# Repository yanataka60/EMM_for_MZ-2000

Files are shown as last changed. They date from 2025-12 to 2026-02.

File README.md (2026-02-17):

# EMMボード for MZ-2000

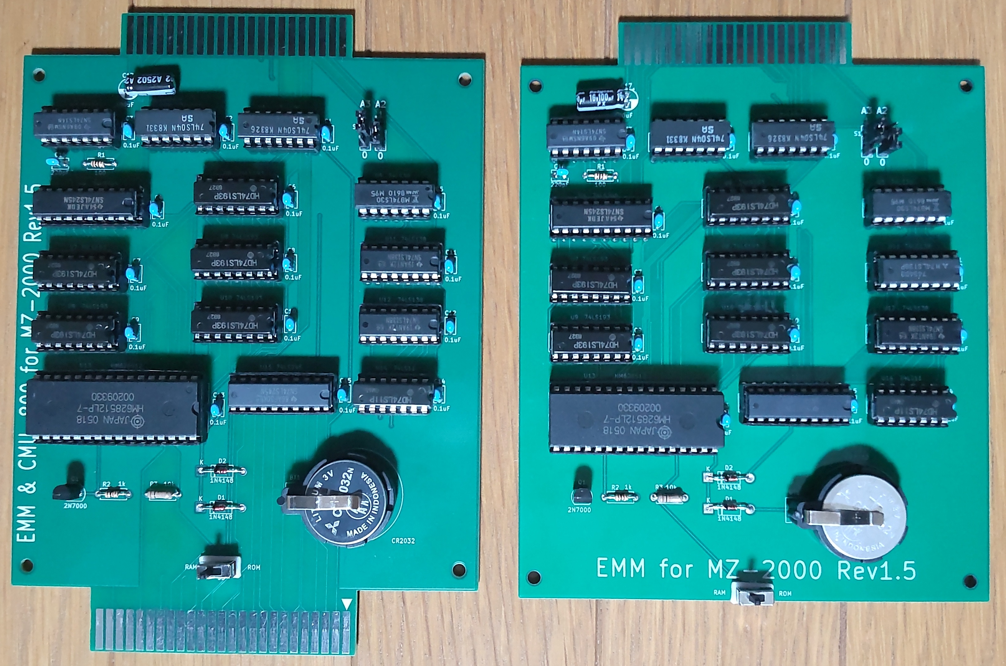
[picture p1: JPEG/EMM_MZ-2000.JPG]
TITLE


　MZ-2000、MZ-2200、MZ-80B、MZ-2500(2000モード、80Bモード)用の512K S-RAM EMMボードを作ってみました。

　特徴としては、

　1)I/Oポートは、I・Oデータ機器 PIO-3034互換なのでそのままPIO-3034(320K EMM)として使えます。

　2)CR-2032のバックアップにより電源を切ってもメモリ内容が保持されます。(Rev1.5のバックアップ期間は計算上数年は大丈夫です。)

　3)スイッチにより書込み禁止にできます。

　4)I/Oポートから直接EMMを読み書きすれば512K外部RAMとして使えます。

　5)MZ-2000_SDと併用すれば512KまるごとSDカードからLOAD、SAVEが可能です。

　6)ジャンパによりEMM0～EMM3のいずれかに設定して使えます。(MZ-2000_SDと併用するときはEMM0としては使えません。EMM1～EMM3として使ってください。)

　7)おまけでアドレスカウンタリセットを付けました。

　なお、MZ-2000、MZ-2200、MZ-80B、MZ2500本体の通常の電源ON/OFFでの正常動作は確認していますが、電源ON/OFFを瞬間的に繰り返すような無理な使い方をするとEMMのバックアップが正常に動作しないことがあります。電源ON/OFFを瞬間的に繰り返すと電源ユニットにもダメージが及ぶこともあるので電源ON/OFFは間をおいて行ってください。

## 回路図
　KiCadフォルダ内にEMMとEMM&CMUの２種類があります。CMU-800を接続するにはCMU-800から出ているフラットケーブルのカードエッジコネクタを接続する必要があり、CMU-800所有者がスロット不足に悩まなくて済むようカードエッジをつけ足したもので回路は全く同じものです。

　お好きな方を使ってください。

[回路図](https://github.com/yanataka60/EMM_for_MZ-2000/blob/main/Kicad/EMM/MZ-2000_EMM.pdf)
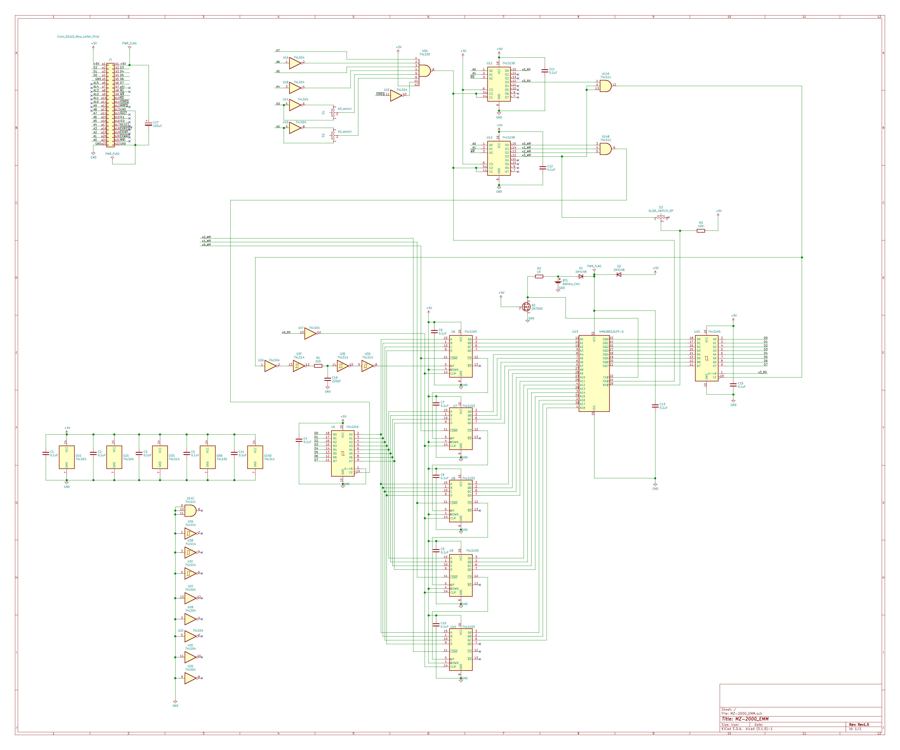
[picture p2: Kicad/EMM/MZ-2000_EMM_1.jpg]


[回路図](https://github.com/yanataka60/EMM_for_MZ-2000/blob/main/Kicad/EMM%26CMU/MZ-2000_EMM_CMU.pdf)
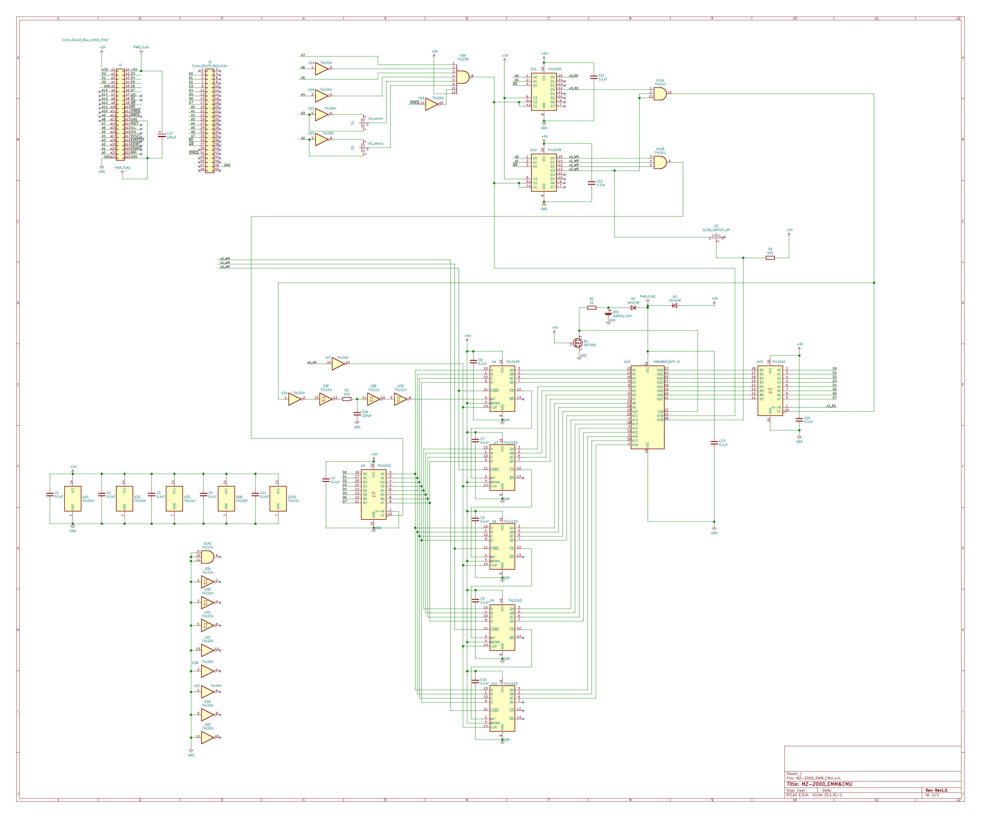
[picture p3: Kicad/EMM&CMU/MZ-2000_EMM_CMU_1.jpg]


## 部品表
|番号|品名|数量|備考|
| --- | --- | --- | --- |
|C1-C15|積層セラミックコンデンサ 0.1uF|15||
|C16|積層セラミックコンデンサ 220pF|1||
|C17|電解コンデンサ 100uF|1||
|D1-D2|ダイオード 1N4148|2|1S4から1N4148に変更|
|Q1|FET 2N7000|1||
|R1|カーボン抵抗 100Ω|1||
|R2|カーボン抵抗 1k|1||
|R3|カーボン抵抗 10k|1||
|S1,S2|3Pスライドスイッチ又は1x3ピンヘッダとジャンパーピン|2|秋月電子通商 SS12D01G4又はPH-1X3SG,MJ-254-6BK等|
|S3|3Pスライドスイッチ|1|秋月電子通商 SS12D01G4|
|U1,U2|74LS04|2|樫木総業等|
|U3|74LS14|1|樫木総業等|
|U4,U15|74LS245|2|樫木総業等|
|U5|74LS30|1|樫木総業等|
|U6-U10|74LS193|5|樫木総業等|
|U11,U12|74LS138|2|樫木総業等|
|U13|SRAM HM628512|1|注1)|
|U14|74LS11|1|樫木総業等|
|BT1|ボタン電池基板取付用ホルダー CR2032用(小型タイプ)|1|秋月電子通商 CH25-2032LFなど|

注1)DIPで設計しています。SOPを入手した場合にはこちらの変換基板を使うことで装着できます。

https://github.com/yanataka60/SOPtoDIP32

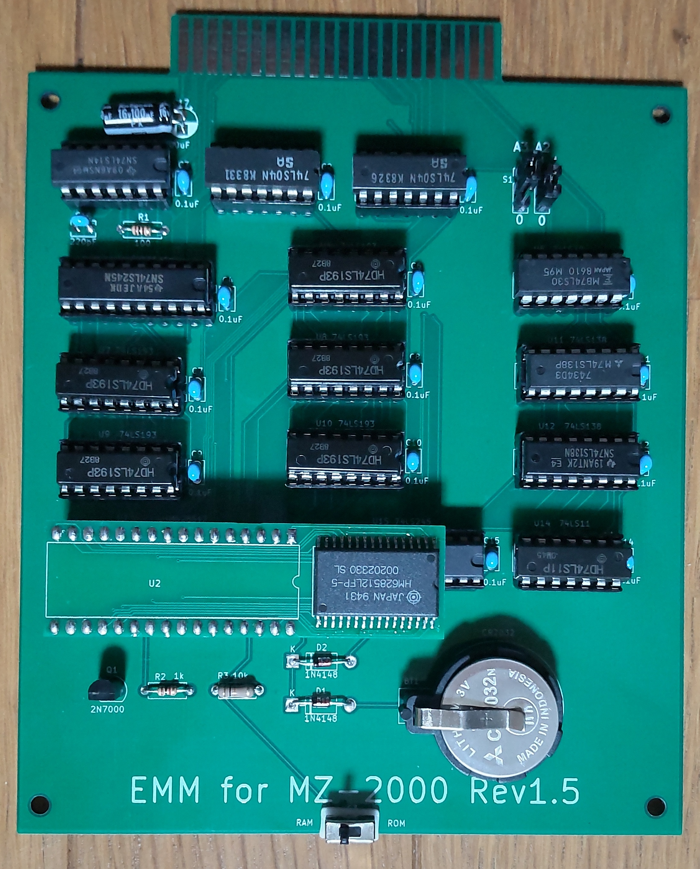
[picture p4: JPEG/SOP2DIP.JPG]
SOP2DIP


## I/Oポート
### EMM0
ジャンパピンA3、A2とも0の位置にします。

#### 注)EMM0の設定ではMZ-2000_SDと共存できません。MZ-2000_SDと共存させたい場合は、EMM1～EMM3の設定で使ってください。

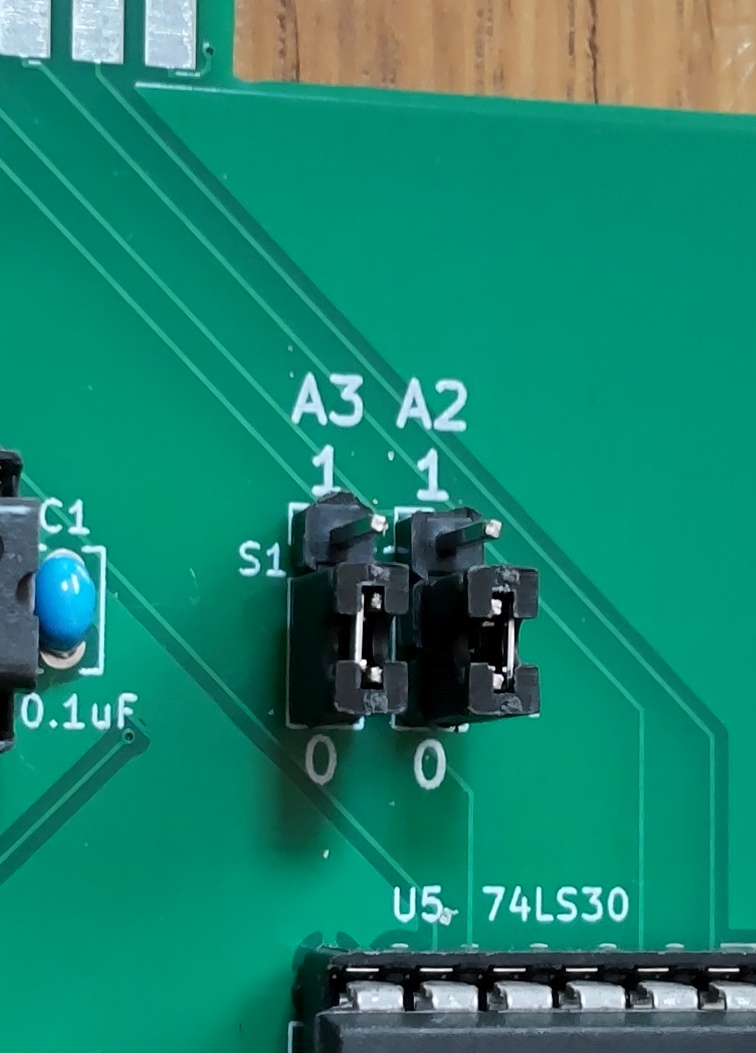
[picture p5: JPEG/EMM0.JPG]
EMM0


|アドレス|R/W|説明|
| --- | --- | --- |
|A0h|R|アドレスカウンタリセット|
|A0h|W|アドレスカウンタ Bit[7:0]|
|A1h|W|アドレスカウンタ Bit[15:8]|
|A2h|W|アドレスカウンタ Bit[18:16]|
|A3h|R|データ読み出し:アドレスカウンタ+1|
|A3h|W|データ書き込み:アドレスカウンタ+1|
### EMM1
ジャンパピンA3を0、A2を1の位置にします。

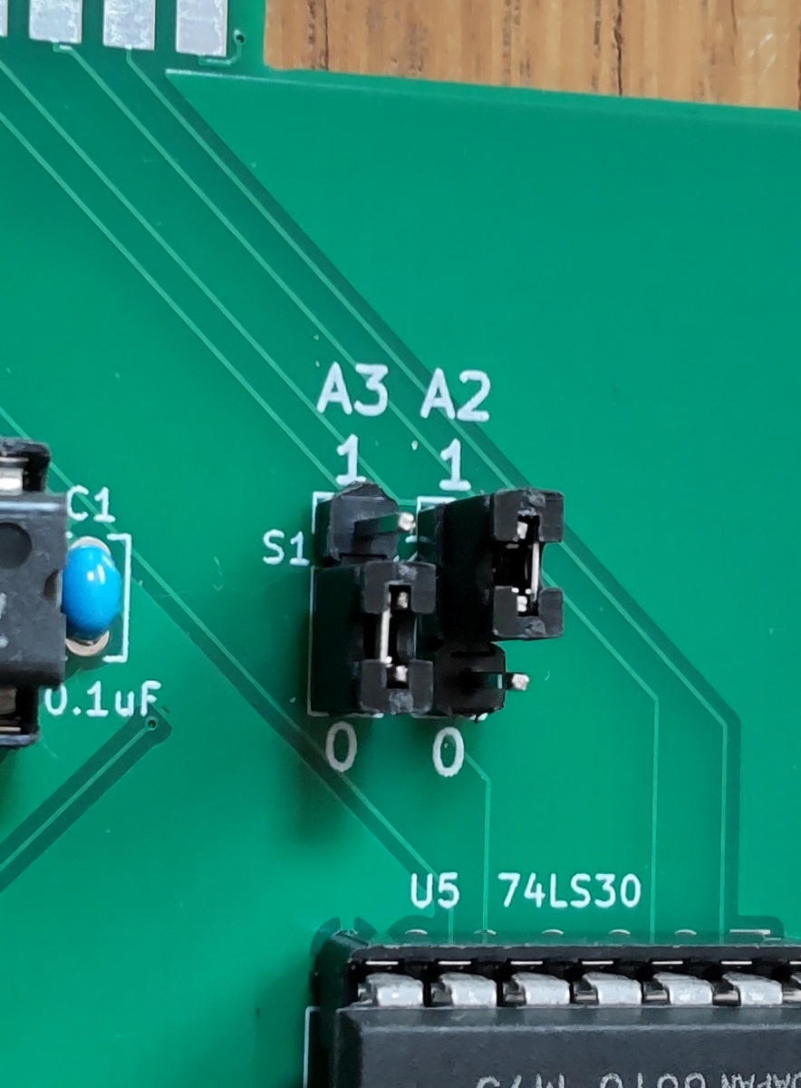
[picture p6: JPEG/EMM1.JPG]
EMM1


|アドレス|R/W|説明|
| --- | --- | --- |
|A4h|R|アドレスカウンタリセット|
|A4h|W|アドレスカウンタ Bit[7:0]|
|A5h|W|アドレスカウンタ Bit[15:8]|
|A6h|W|アドレスカウンタ Bit[18:16]|
|A7h|R|データ読み出し:アドレスカウンタ+1|
|A7h|W|データ書き込み:アドレスカウンタ+1|
### EMM2
ジャンパピンA3を1、A2を0の位置にします。

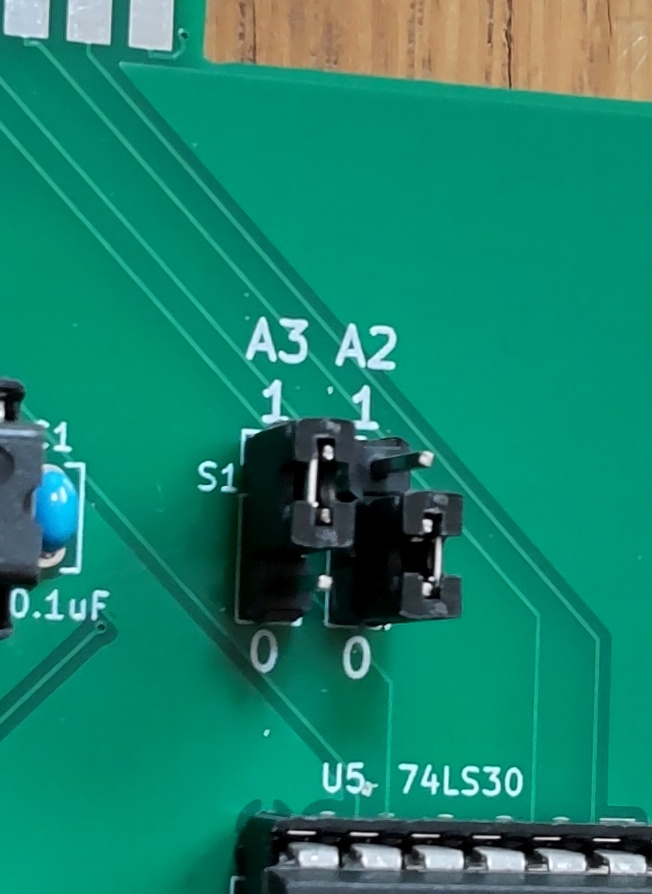
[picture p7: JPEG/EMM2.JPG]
EMM2


|アドレス|R/W|説明|
| --- | --- | --- |
|A8h|R|アドレスカウンタリセット|
|A8h|W|アドレスカウンタ Bit[7:0]|
|A9h|W|アドレスカウンタ Bit[15:8]|
|AAh|W|アドレスカウンタ Bit[18:16]|
|ABh|R|データ読み出し:アドレスカウンタ+1|
|ABh|W|データ書き込み:アドレスカウンタ+1|
### EMM3
ジャンパピンA3、A2とも1の位置にします。

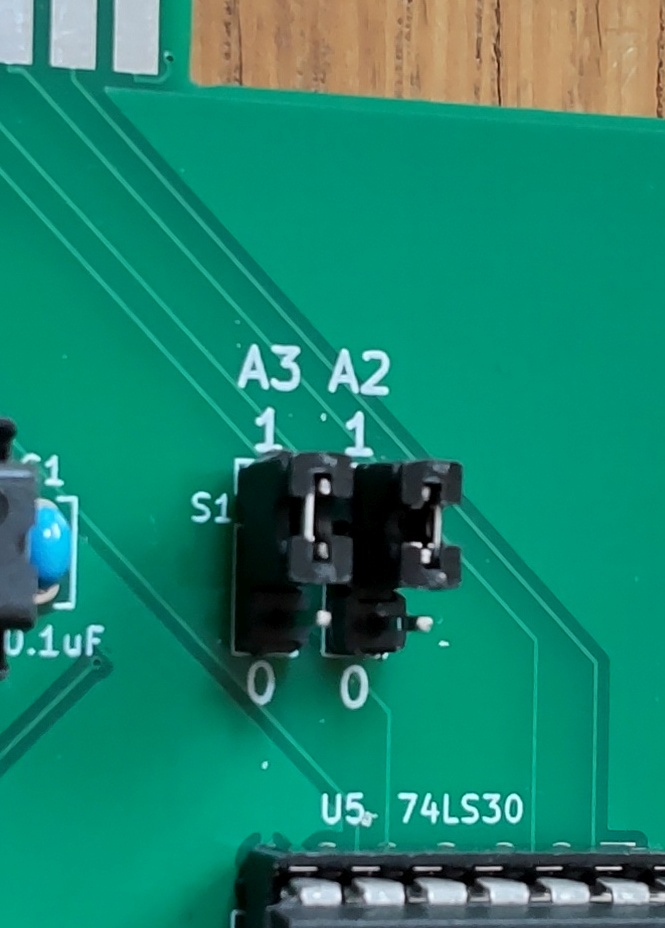
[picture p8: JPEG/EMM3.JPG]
EMM3


|アドレス|R/W|説明|
| --- | --- | --- |
|ACh|R|アドレスカウンタリセット|
|ACh|W|アドレスカウンタ Bit[7:0]|
|ADh|W|アドレスカウンタ Bit[15:8]|
|AEh|W|アドレスカウンタ Bit[18:16]|
|AFh|R|データ読み出し:アドレスカウンタ+1|
|AFh|W|データ書き込み:アドレスカウンタ+1|

## SAMPLEプログラム
　SAMPLEフォルダ内にEMMANIME、EMMMENU、EMMCHECK、EMMTESTを置きました。

　使い方については、各フォルダ内のREADME.mdを参照してください。

## EMMからの起動
　せっかくバッテリーバックアップに対応させたのでMZ-2000_SDの起動時にEMMから起動できるようにしてみました。

　MZ-2000_SDのROMをEMM対応BOOT LOADERに書き換える必要があります。

　MZ-2000_SDの「EMMボード for MZ-2000からの起動」を参照してください。

　https://github.com/yanataka60/MZ-2000_SD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

## 初期基板をバッテリーバックアップ対応とするには
#### 2026.2.16 Rev1.5基板ではバックアップ時間が飛躍的に増加し、ICに負荷をかけない回路となりました。バッテリーバックアップを使うなら出来ればRev1.5基板に更新してください。

　以下に示すパターンカット、ジャンパ、追加部品(抵抗10k×1本、ダイオード1S4×1本)で改造することで初期基板をバッテリーバックアップ対応とすることが可能です。

　ただし、パターンカット個所がU2 74LS04 ICソケット内側にもあるのでEMMボード組み立て済みの場合にはICソケットを一旦取り外す必要があります。

　また、EMM基板とEMM&CMU基板ではパターンカットの個所が若干違いがあります。ジャンパは共通です。

### EMM基板パターンカット個所
　U2 74LS04の3Pin、5Pin、9Pin、11PinをGNDから切り離します。

　U13 HM628512の29PinとU14 74LS11 13Pinとの接続をカットします。

　U13 HM628512の22、24Pin、R2 抵抗 10Kとの接続点とU12 74LS138 5Pinとの接続をカットします。

部品面全体
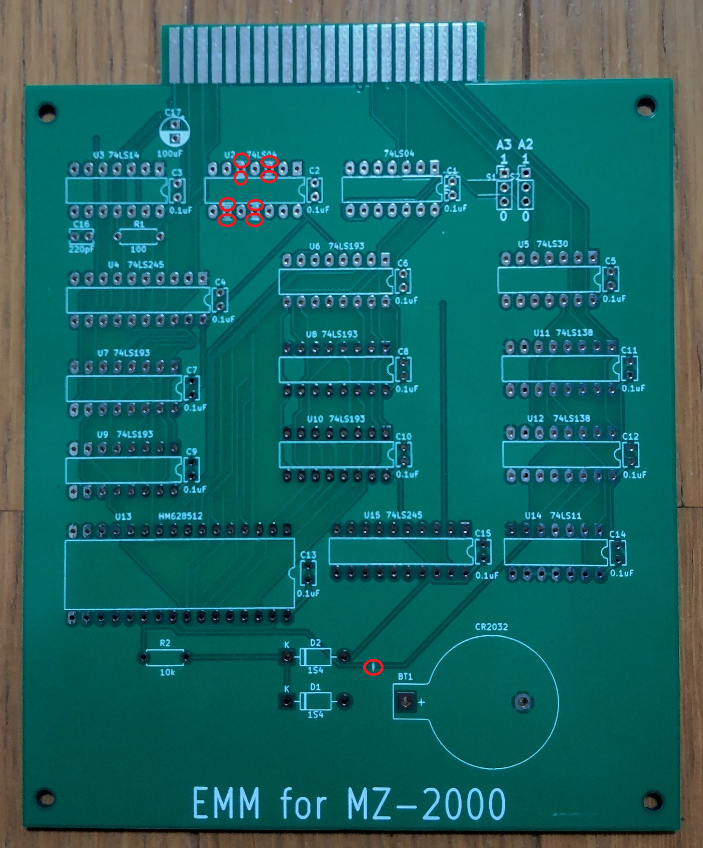
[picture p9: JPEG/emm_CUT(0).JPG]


部品面拡大1
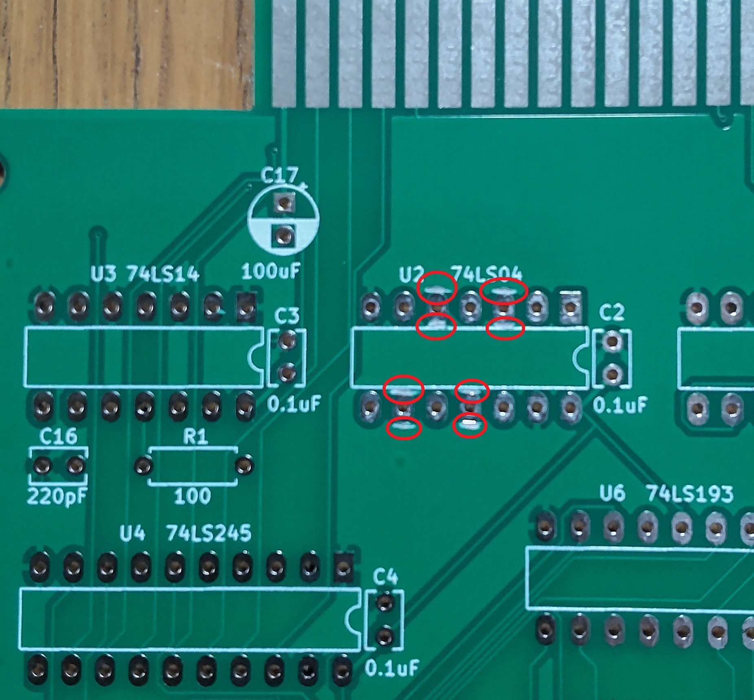
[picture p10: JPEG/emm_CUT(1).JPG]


部品面拡大2
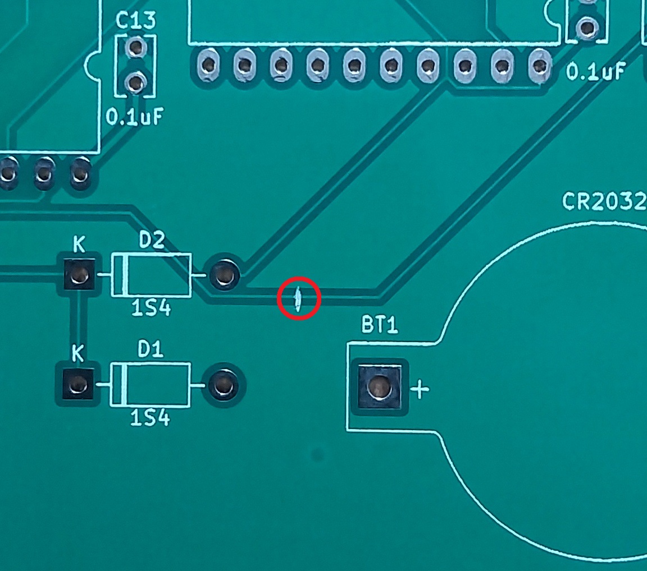
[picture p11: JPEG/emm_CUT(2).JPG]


ハンダ面全体
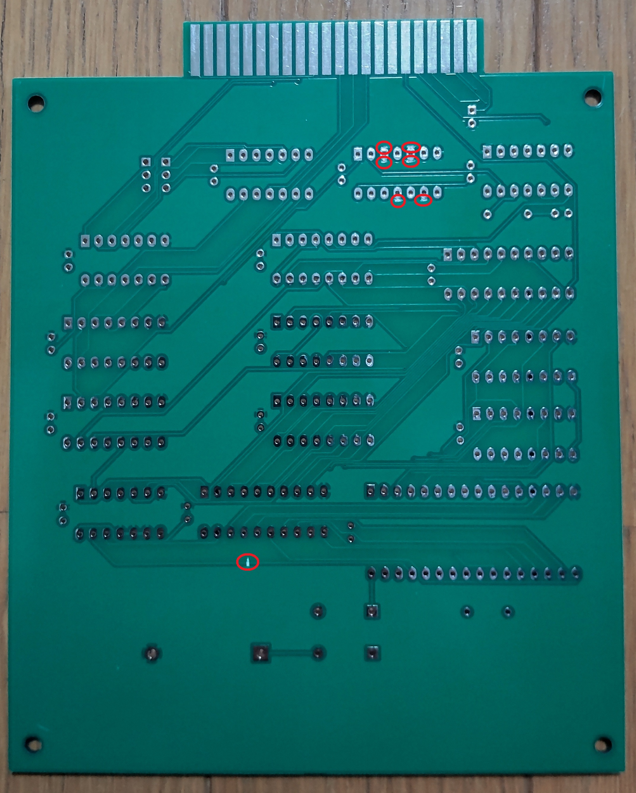
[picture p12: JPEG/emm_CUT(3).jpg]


ハンダ面拡大1
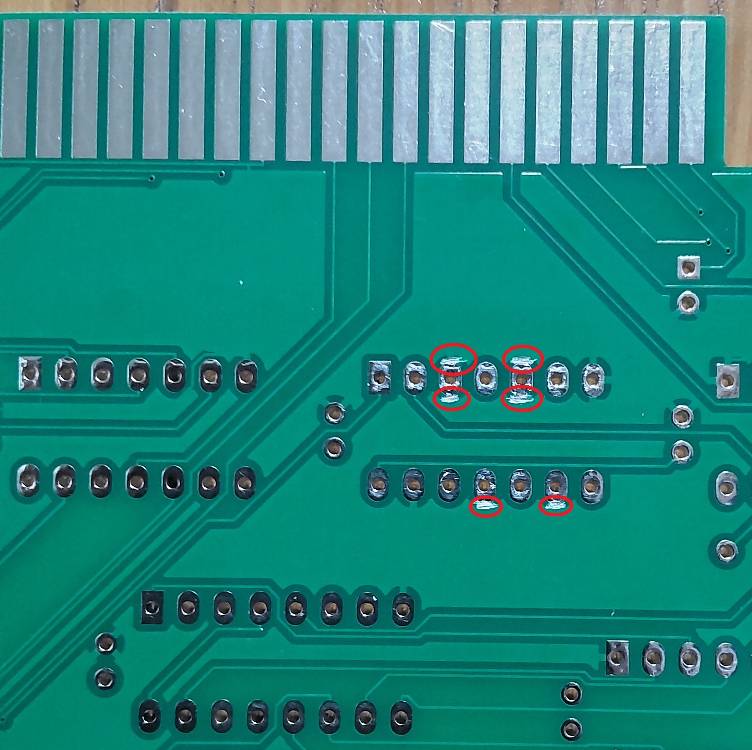
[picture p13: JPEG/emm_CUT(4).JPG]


ハンダ面拡大2
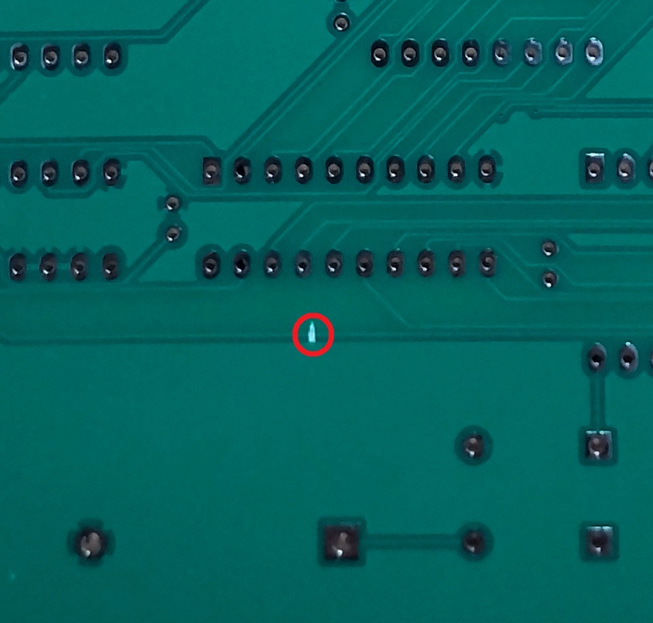
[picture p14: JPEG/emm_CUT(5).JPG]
cut5


### EMM&CMU基板パターンカット個所
　切り離すポイントはEMM基板と同じですが、基板上のカット位置は若干異なります。

部品面全体
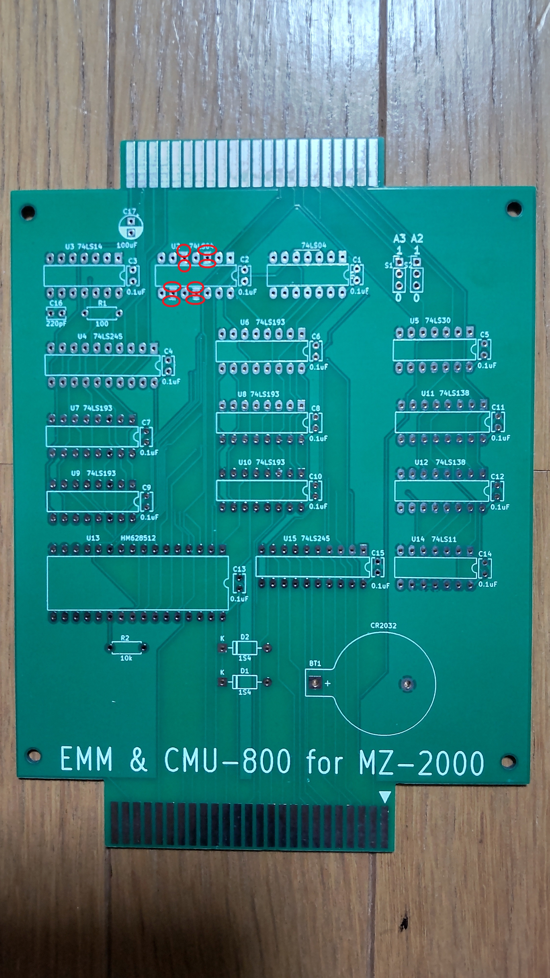
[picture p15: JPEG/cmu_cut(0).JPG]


部品面拡大1
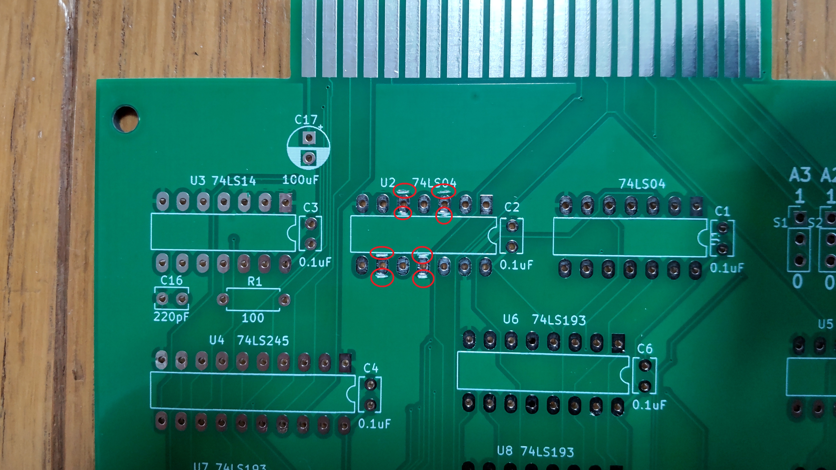
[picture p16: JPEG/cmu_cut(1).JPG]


ハンダ面全体
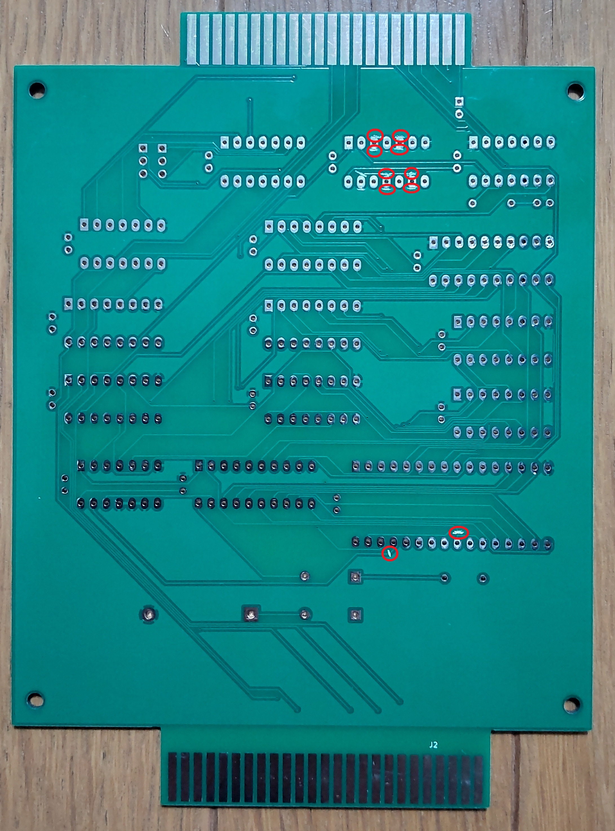
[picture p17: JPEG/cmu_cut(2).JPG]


ハンダ面拡大1
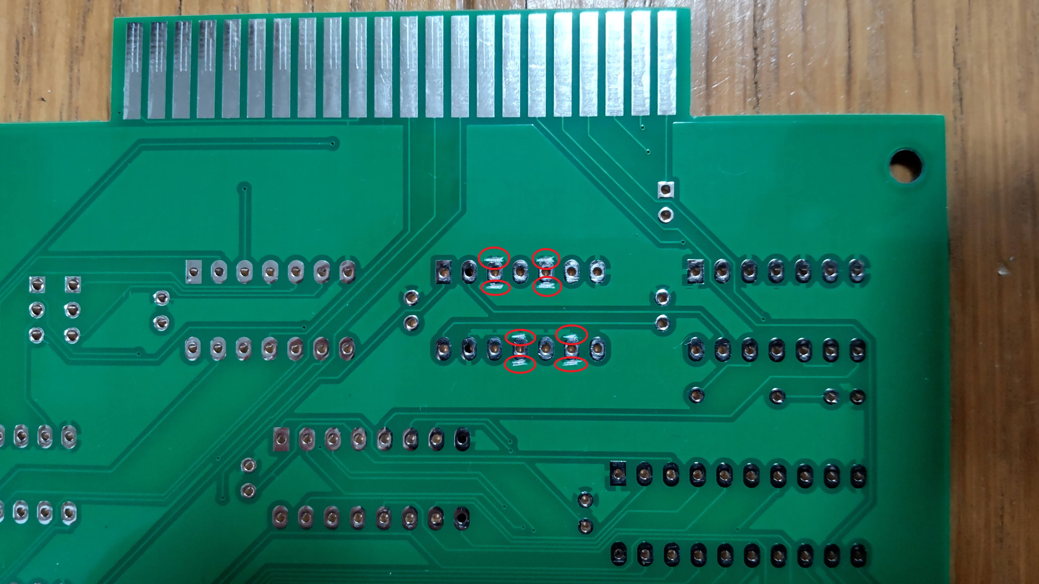
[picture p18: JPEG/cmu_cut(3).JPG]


ハンダ面拡大2
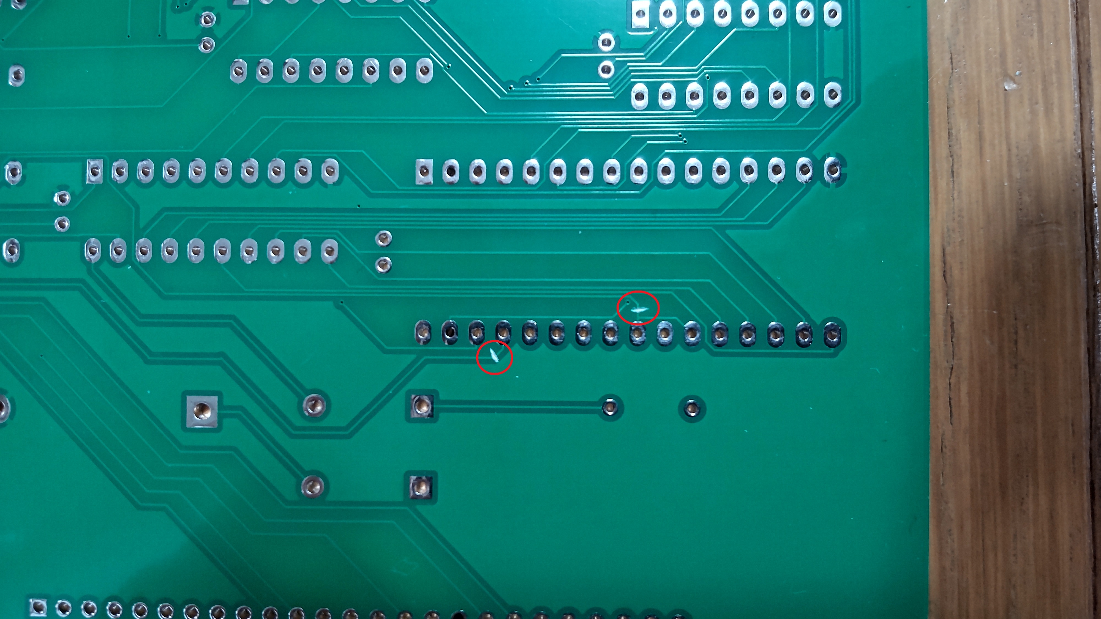
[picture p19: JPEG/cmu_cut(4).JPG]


### ジャンパ個所
　U12 74LS138 5PinとU2 74LS04 3Pin

　U2 74LS04 4Pinと5Pin

　U2 74LS04 6PinとU13 HM628512 24Pin

　U12 74LS138 12PinとU2 74LS04 11Pin

　U2 74LS04 10Pinと9Pin

　U2 74LS04 8Pinとダイオード 1S4 アノード

　ダイオード 1S4 カソードとU13 HM628512 29Pin

　U13 HM628512 29Pinと抵抗 10KとU13 HM628512 32Pin

ハンダ面全体
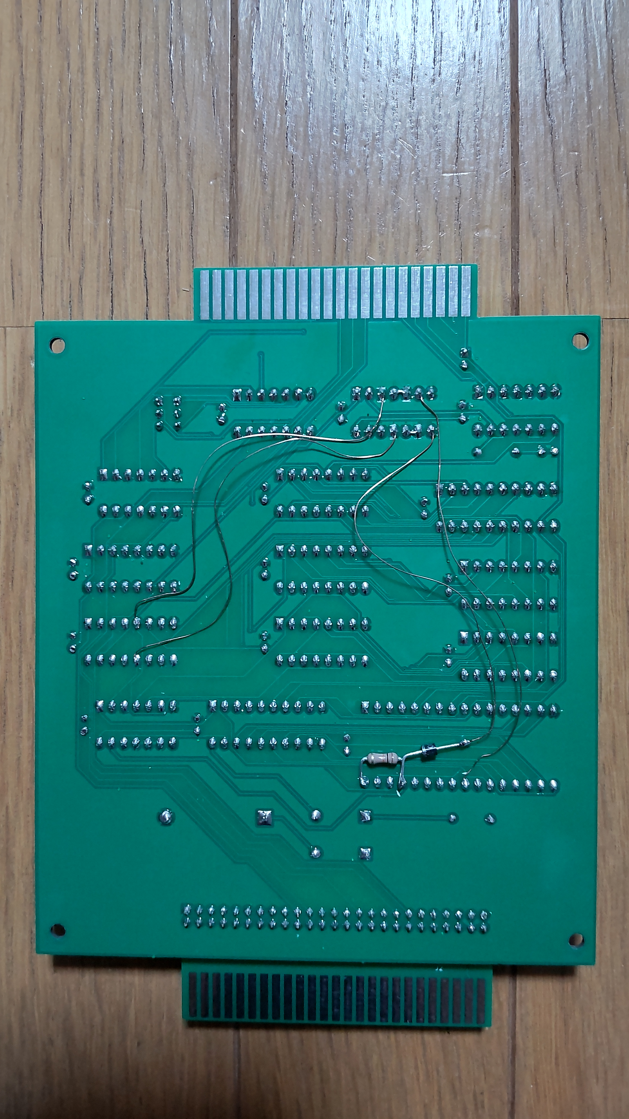
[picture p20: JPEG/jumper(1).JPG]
jumper1


ハンダ面拡大1
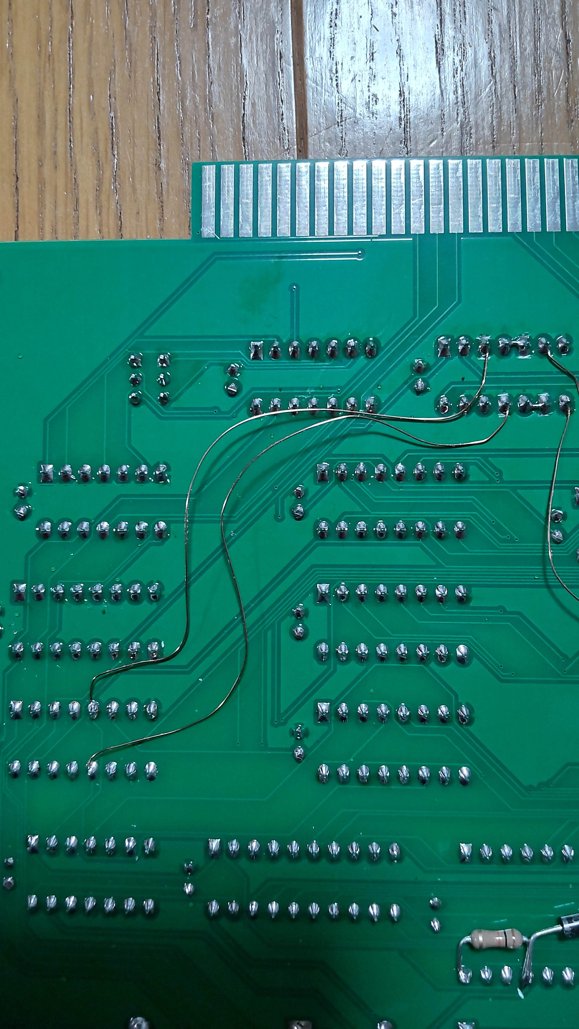
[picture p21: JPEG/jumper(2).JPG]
jumper2


ハンダ面拡大2
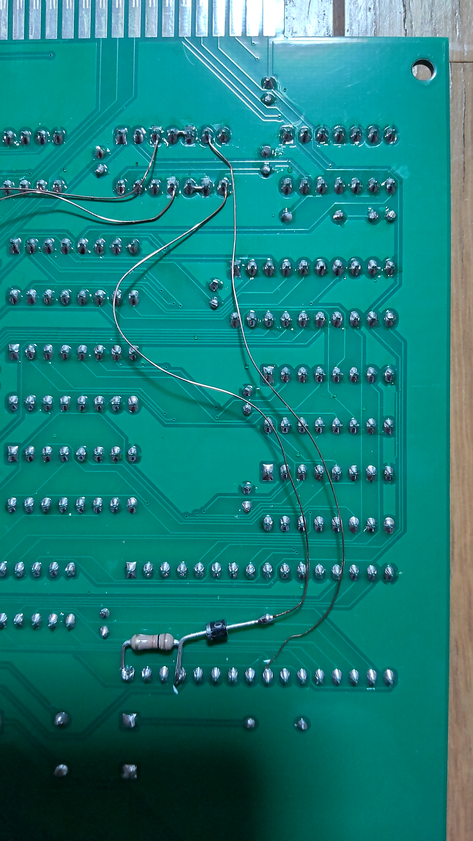
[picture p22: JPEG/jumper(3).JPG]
jumper3


## 追記
2025.12.20 SAMPLEプログラムを追加しました。

2025.12.23 EMMLOAD、EMMSAVEを統合し、EMMMENUとしました。

2025.12.23 EMMANIME2000、EMMANIME80Bを統合し、EMMANIMEとしました。

2025.12.27 EMMMENUにSDアクセスルーチンを内包しました。

2025.12.28 バッテリーバックアップしていてもメモリ内容が変わってしまう症状が時々発生しています。原因と対策を検討中です。

2026.1.1 簡単な修正では症状を抑えることが出来ないのでこのバージョンではバッテリーバックアップは断念し、対策を練りなおします。

2026.1.22 バッテリーバックアップ正常版(Rev1.2)に更新。初期基板をバッテリーバックアップ対応とするための改修方法を記述。

2026.1.23 バックアップ期間について追記。

2026.1.24 HM628512の書き込み時WE信号が瞬間的に5.9Vほどの電圧が掛かることを記述。すーぱーたーぼさんご指摘ありがとうございました。

2026.1.25 D1,D2を1S4から1N4148に変更。AIGOU Yoshiakiさんアドバイスありがとうございました。

2026.2.16 すーぱーたーぼさんに提案していただいていたn-FETを用いたバッテリーバックアップ回路を採用しました。すーぱーたーぼさんアドバイスありがとうございました。

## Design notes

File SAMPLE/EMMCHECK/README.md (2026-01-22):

# EMMCHECK for MZ-2000_SD

　EMMボートの512K S-RAMの内容とMZ-2000_SDのファイルの内容を比較します。

MZ-2000、MZ-80B、MZ-2500の2000モード・80Bモードで実行可能です。

　バッテリーバックアップが正常に機能しているかチェックするためのプログラムです。

　起動するとまず対象とするEMMをEMM1～EMM3の中から数字で選択します。

　次に比較するファイルを指定します。

　「FNAME:」と聞いてきますので次のうちから選択して入力します。

### [BREAK]キー
　処理が中断されたものとしてMONITOR入力待ちに戻ります。

### DOSファイル名を入力せずそのまま[CR]キー
　選択したEMMに対応するPIO3034_x.mzt(PIO3034_1.mzt、PIO3034_2.mzt、PIO3034_3.mzt)をDOSファイル名として比較します。

### DOSファイル名を入力して[CR]キー
　入力されたDOSファイル名のファイルと比較とします。拡張子の「mzt」は省略可能です。

### *FDL xxx[CR]キー
　SDカードに保存されている文字列xxxから始まるDOSファイル名を一覧表示します。xxxを省略した場合はすべてのファイルが一覧表示対象となります。

　20件表示したところで指示待ちになるので打ち切るならSHIFT+BREAK又は↑を入力すると打ち切られ、Bキーで前の20件に戻ります。それ以外のキーで次の20件を表示します。

　検索結果の行頭には「FNAME:」を付加して表示してあるので比較したいファイルにカーソルキーを合わせて[CR]キーを押すだけで選択が可能です。

例)

FNAME:[CR]

FNAME:PIO-3034EMM1[CR]

FNAME:*FDL PIO[CR]

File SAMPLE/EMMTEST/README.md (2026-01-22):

# EMMTEST

　EMMボートの512K S-RAMの読み書きテストプログラムです。

　MZ-2000、MZ-80B、MZ-2500の2000モード・80Bモードで実行可能です。

　RAMの内容を一時退避しながらテストしますのでRAMの読み書きが正常であればEMMの内容が変化してしまうことはありません。

　起動すると対象とするEMMをEMM0～EMM3の中から数字で選択するとテストが始まります。(00000h～7FFFFh)

　書き込んだ内容が正常に読み出せない場合にはエラーと表示して停止します。

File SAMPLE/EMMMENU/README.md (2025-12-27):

# EMMMENU(SDからEMMへLOAD、EMMからSDへSAVE) for MZ-2000_SD

MZ-2000_SDを使い、EMMボートの512K S-RAMの内容をまるごとSDへSAVE、またSDにSAVEされたS-RAMの内容をまるごとEMMボートへLOADするプログラムです。

MZ-2000、MZ-80B、MZ-2500の2000モード・80Bモードで実行可能です。

~~SDアクセスルーチンがF800h以降に存在する起動直後のMZ-2000_SDでの利用を想定しています。~~(2025.12.27 SDアクセスルーチンを内包しました。)

~~F800h以降にSDアクセスルーチンが無い状態で実行すると暴走します。~~

SDカードに保存されたEMM DUMPファイルはMZTファイルのヘッダが付加され512KB+128Byte=524416Byteになります。

なお、EMM DUMPファイルはWindowsパソコンのエミュレーター2種類で利用可能であることを確認しています。

## 利用可能なエミュレーター

### kuran_kuranさんのEmuZ-80B/2200

武田さんの Common Source Code Project EmuZ-2200/EmuZ-80Bをkuran_kuranさんがMZ2000_SD、CMU-800、PIO-3034に対応させたエミュレーターです。

https://github.com/kuran-kuran/CommonSourceCodeProject/releases

　EMM DUMPファイルから128Byteのヘッダを除去し、PIO3034_x.BIN(PIO3034_0.BIN、PIO3034_1.BIN、PIO3034_2.BIN、PIO3034_3.BIN)にリネームしてmz2200.exeと同じフォルダに置けばエミュレーターから利用できるようになります。

　また、PIO3034_x.BIN(PIO3034_0.BIN、PIO3034_1.BIN、PIO3034_2.BIN、PIO3034_3.BIN)に128Byteのヘッダをつけて拡張子をmztとすればEMM DUMPファイルとして使えます。

　この時、付加する128Byteのヘッダの内容はどんな内容でも構わないので00hを128Byte等好きにつけてください。

### FUKUI, Toshioさんの"emz2000 / EmuZ-2000" TF-Edition

http://fukui.s17.xrea.com/retro/mz2080b/emulator.html

　kuran_kuranさんのEmuZ-80B/2200と基本的には同様です。

　EMM DUMPファイルから128Byteのヘッダを除去し、PIO-3034EMMx.MEM(PIO-3034EMM0.MEM、PIO-3034EMM1.MEM、PIO-3034EMM2.MEM、PIO-3034EMM3.MEM)にリネームしてEmuZ2000TF.exeと同じフォルダに置けばエミュレーターから利用できるようになります。

　ただし、"emz2000 / EmuZ-2000" TF-Editionは320KB EMMしかサポートしていないようです。512KBのPIO-3034EMMx.MEMを置いても"emz2000 / EmuZ-2000" TF-Editionで利用した後には320KBのPIO-3034EMMx.MEMになってしまいます。

　PIO-3034EMMx.MEM(PIO-3034EMM0.MEM、PIO-3034EMM1.MEM、PIO-3034EMM2.MEM、PIO-3034EMM3.MEM)に128Byteのヘッダをつけて拡張子をmztとすればEMM DUMPファイルとして使えます。ファイル長は320KB+128Byte=327808Byteですが、EMMへのLOADにそのまま使えます。

　付加する128Byteのヘッダの内容はどんな内容でも構わないので00hを128Byte等好きにつけてください。

## EMMMENUの使い方
　起動するとまず対象とするEMMをEMM1～EMM3の中から数字で選択します。

　次にEMMLOAD、EMMSAVE、EXITを数字で選択します。

## EMMLOADの使い方
　SDからEMMへの転送にかかる時間は約90秒です。

　起動すると「FNAME:」と聞いてきますので次のうちから選択して入力します。

### [BREAK]キー
　処理が中断されたものとしてMONITOR入力待ちに戻ります。

### DOSファイル名を入力せずそのまま[CR]キー
　選択したEMMに対応するPIO3034_x.mzt(PIO3034_1.mzt、PIO3034_2.mzt、PIO3034_3.mzt)をDOSファイル名としてSDカードからEMMに転送します。

### DOSファイル名を入力して[CR]キー
　入力されたDOSファイル名のファイルをSDカードからEMMに転送します。拡張子の「mzt」は省略可能です。

### *FDL xxx[CR]キー
　SDカードに保存されている文字列xxxから始まるDOSファイル名を一覧表示します。xxxを省略した場合はすべてのファイルが一覧表示対象となります。

　20件表示したところで指示待ちになるので打ち切るならSHIFT+BREAK又は↑を入力すると打ち切られ、Bキーで前の20件に戻ります。それ以外のキーで次の20件を表示します。

　検索結果の行頭には「FNAME:」を付加して表示してあるのでLOADしたいファイルにカーソルキーを合わせて[CR]キーを押すだけでLOADが可能です。

例)

FNAME:[CR]

FNAME:PIO-3034EMM1[CR]

FNAME:*FDL PIO[CR]

## EMMSAVEの使い方
#### 注)SDカードに多くのファイルが登録されているとEMMSAVEに時々失敗することがあり、失敗するとMZ-2000_SDからSDカードにアクセス不可能になってしまう事象が発生します。

#### EMMxSAVE.mztを実行するときはなるべく必要最小限のファイル(@BOOT-A MZ-2000.bin、@BOOT-B MZ-2000.bin、@BOOT-A MZ-80B.bin、@BOOT-B MZ-80B.bin、EMMMENU.mzt)だけが登録された専用のSDカードでの実行で行ってください。

#### MZ-2000_SDからアクセス不可能になったSDカードもWindowsからは問題なくアクセスできるのでSDカードから作成に失敗したPIO3034-x-SAVE.mztを削除したのちにすべての内容を一旦Windowsのフォルダに移動させ、SDカードにファイルが一つもない状態にしてから退避したWindowsのフォルダからすべてのファイルを戻すことで復旧できます。

　EMMからSDへの保存にかかる時間は約100秒です。

　選択すると先に選択していたEMMによりPIO3034-x-SAVE.mzt(PIO3034-1-SAVE.mzt、PIO3034-2-SAVE.mzt、PIO3034-3-SAVE.mzt)というファイルがSDカードに作成されます。

　同名のファイルがあると上書きされます。SDに保存されるファイル名はPIO3034-x-SAVE.mzt(PIO3034-1-SAVE.mzt、PIO3034-2-SAVE.mzt、PIO3034-3-SAVE.mzt)に固定されていて指定はできません。

例)

FD EMM1SAVE[CR]

FD EMM2SAVE[CR]

FD EMM3SAVE[CR]

#### SDカードは消耗品ですのでバックアップを怠らないことをお勧めします。

## 追記
2025.12.23 EMM3が選択できなくなっていたので修正。

2025.12.27 SDアクセスルーチンを内包しました。

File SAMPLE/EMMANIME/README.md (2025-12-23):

# EMMのデータでアニメーション

　EMMに格納されているデータをG-RAMに転送することでアニメーションしようというプログラムです。

　MZ-2000とMZ-80Bを自動判別して起動します。

## EMMANIMEの使い方
　EMMには先にデータを作成または転送しておく必要があります。

　EMMANIME.EXEを実行すると実行環境がMZ-2000か、MZ-80Bか自動判別して起動します。

　どのEMMのデータを使うか選択すればそのデータによりアニメーションが始まります。

　止めたいときには何かキーを押せばモニターに戻ります。

## データ
　以下にフォーマットを示しますが、枚数分の画像データにmztファイル用のヘッダが付加された形となっています。

　何らかの方法で画像データを作成しそれらを一つのファイルにまとめてEMMへコピーします。

　MZ-2000_SDを使用していればEMMMENUを使用してEMMへデータをコピーすることが出来ます。

### MZ-2000
|データ長|内容|備考|
| --- | --- | --- |
|0080h|mztファイルヘッダ|00Hを128Byteで可|
|4000h|PAGE01画像データ||
||[30枚分の画像データ]||
|4000h|PAGE32画像データ||

　サンプルとしてPIO3034_1_anime2000.MZTを置いてあります。

### MZ-80B
|データ長|内容|備考|
| --- | --- | --- |
|0080h|mztファイルヘッダ|00Hを128Byteで可|
|2000h|PAGE01画像データ||
||[62枚分の画像データ]||
|2000h|PAGE64画像データ||

　サンプルとしてPIO3034_1_anime80b.MZTを置いてあります。

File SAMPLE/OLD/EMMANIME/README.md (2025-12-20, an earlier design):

# EMMのデータでアニメーション

　EMMに格納されているデータをG-RAMに転送することでアニメーションしようというプログラムです。

　MZ-2000用とMZ-80B用と２種類あるので機種にあった方を使ってください。

## EMMANIMEの使い方
　EMMにデータを転送したのちに機種とEMMに合わせて以下からプログラムを選択し、実行すればアニメーションが始まります。

　止めたいときには何かキーを押せばモニターに戻ります。

### MZ-2000用プログラム
　SAMPLEフォルダ、EMMANIMEフォルダ、EMMANIME2000内のEMM0ANIME2000.mzt、EMM1ANIME2000.mzt、EMM2ANIME2000.mzt、EMM3ANIME2000.mztのいずれかを使います。

　MZ-2000_SDを使っていればSDカードにコピーします。

### MZ-80B用プログラム
　SAMPLEフォルダ、EMMANIMEフォルダ、EMMANIME80B内のEMM0ANIME80B.mzt、EMM1ANIME80B.mzt、EMM2ANIME80B.mzt、EMM3ANIME80B.mztのいずれかを使います。

　MZ-2000_SDを使っていればSDカードにコピーします。

## データ
　以下にフォーマットを示しますが、枚数分の画像データにmztファイル用のヘッダが付加された形となっています。

　何らかの方法で画像データを作成しそれらを一つのファイルにまとめてEMMへコピーします。

　EMMへのコピーはEMMLOADで行います。

### MZ-2000
|データ長|内容|備考|
| --- | --- | --- |
|0080h|mztファイルヘッダ|00Hを128Byteで可|
|4000h|PAGE01画像データ||
||[30枚分の画像データ]||
|4000h|PAGE32画像データ||

　サンプルとしてPIO3034_1_anime2000.MZTを置いてあります。

### MZ-80B
|データ長|内容|備考|
| --- | --- | --- |
|0080h|mztファイルヘッダ|00Hを128Byteで可|
|2000h|PAGE01画像データ||
||[62枚分の画像データ]||
|2000h|PAGE64画像データ||

　サンプルとしてPIO3034_1_anime80b.MZTを置いてあります。

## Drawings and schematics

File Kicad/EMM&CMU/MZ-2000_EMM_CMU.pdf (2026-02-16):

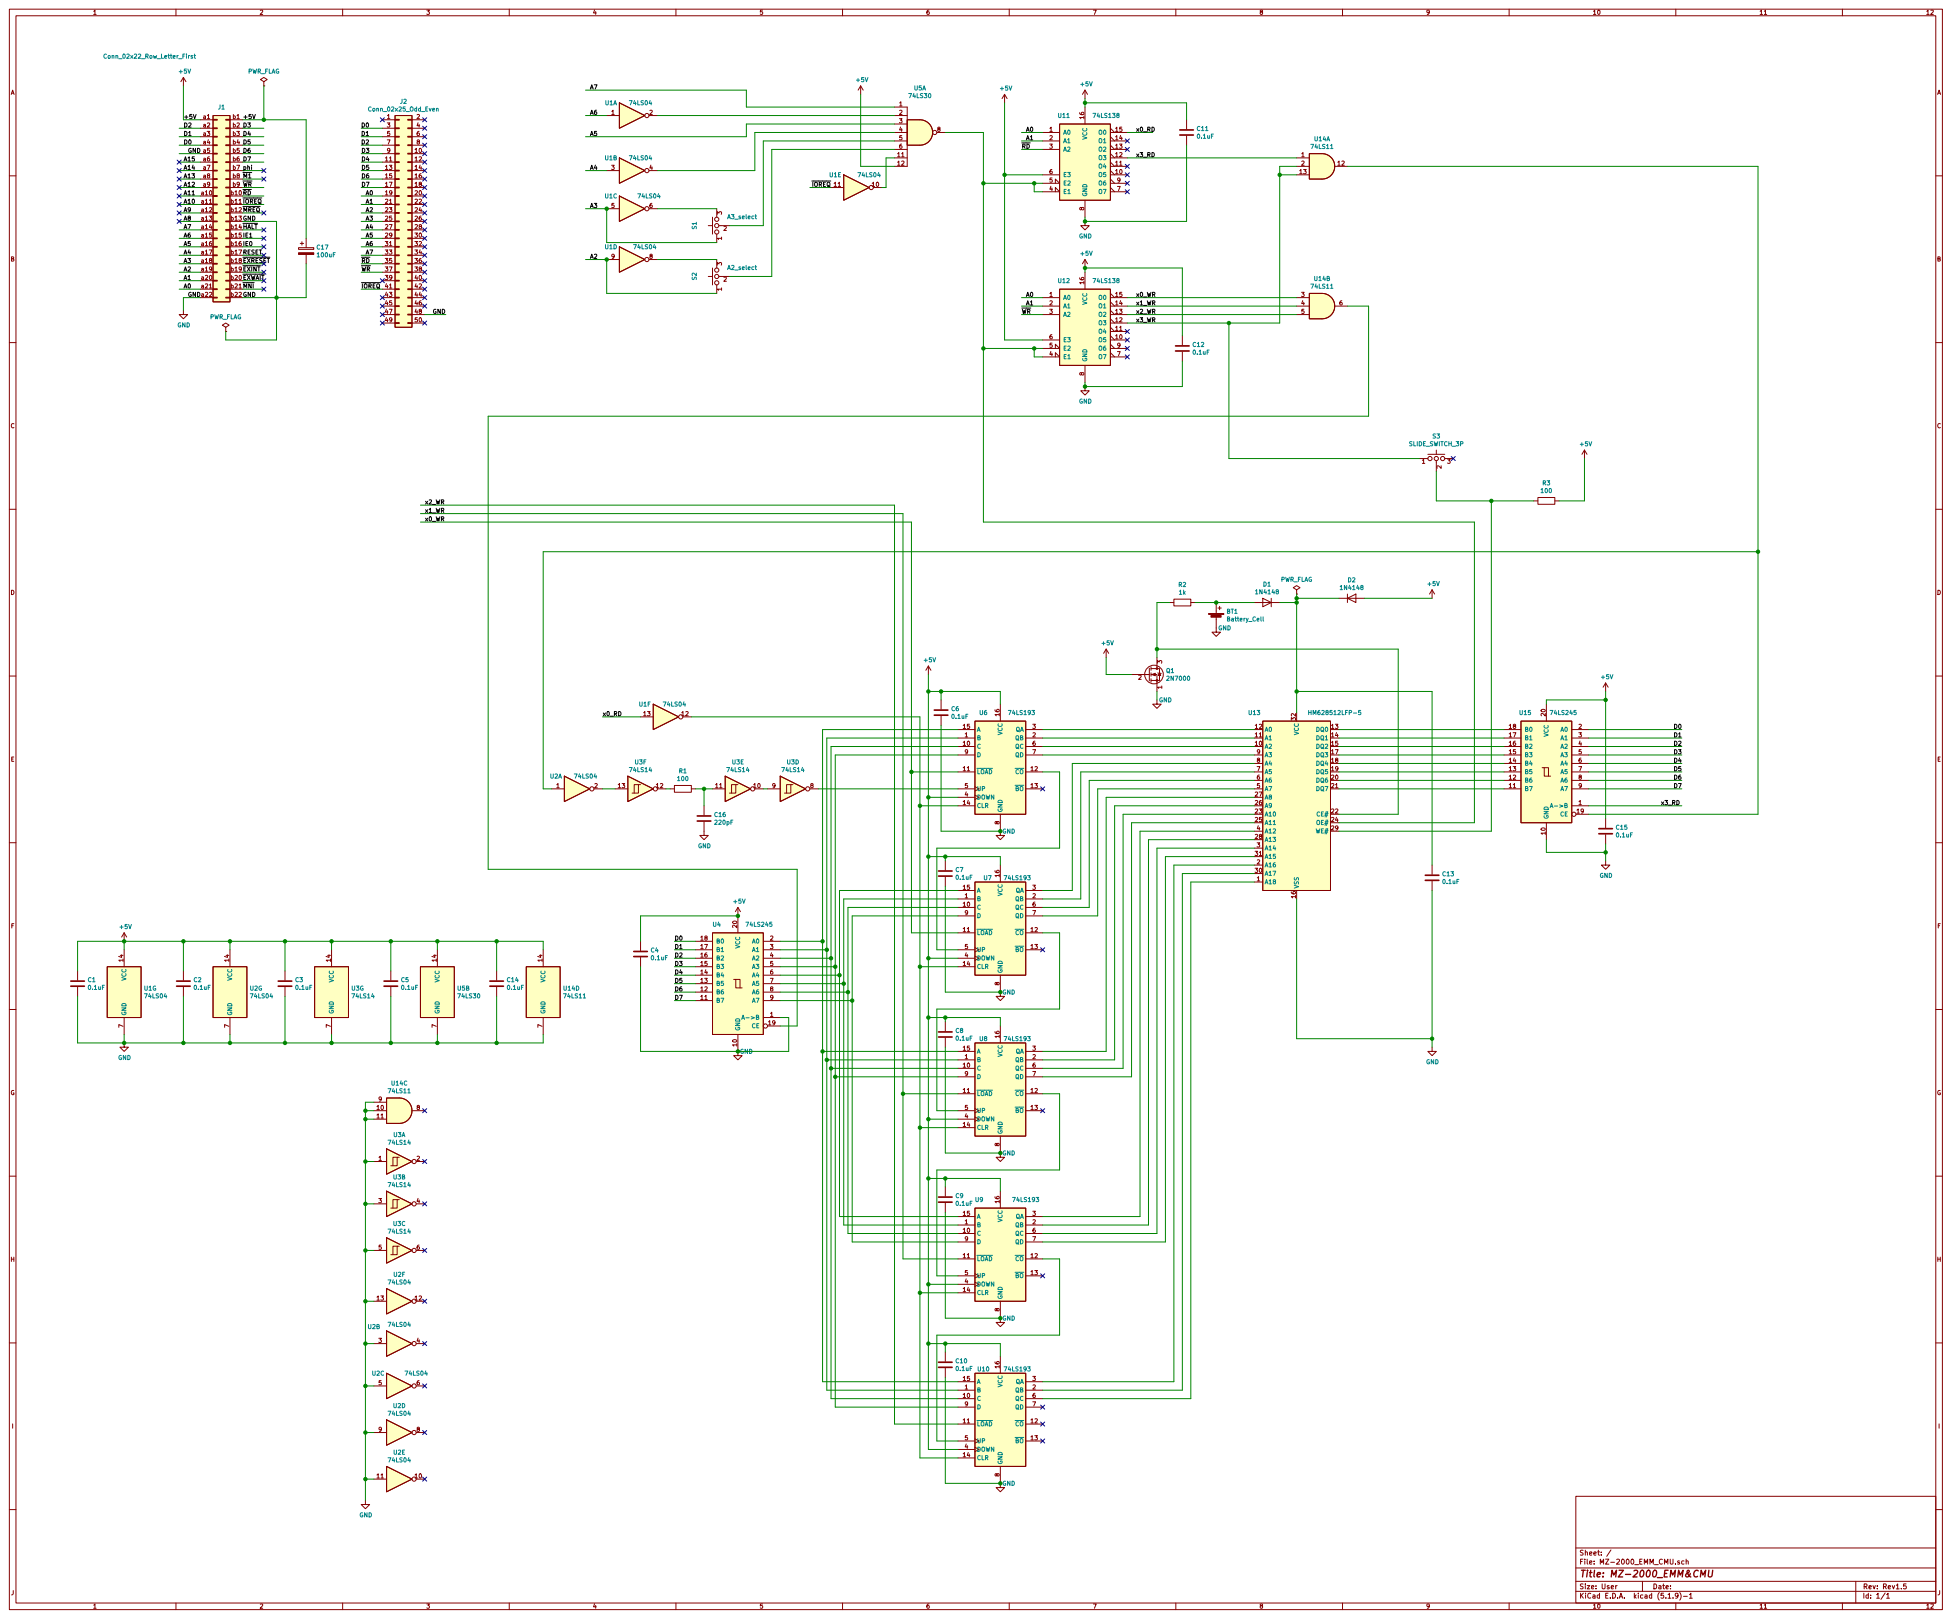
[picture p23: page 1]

11

File: MZ-2000_EMM_CMU.sch Sheet: /
Id: 1/1 Title: MZ-2000_EMM&CMU

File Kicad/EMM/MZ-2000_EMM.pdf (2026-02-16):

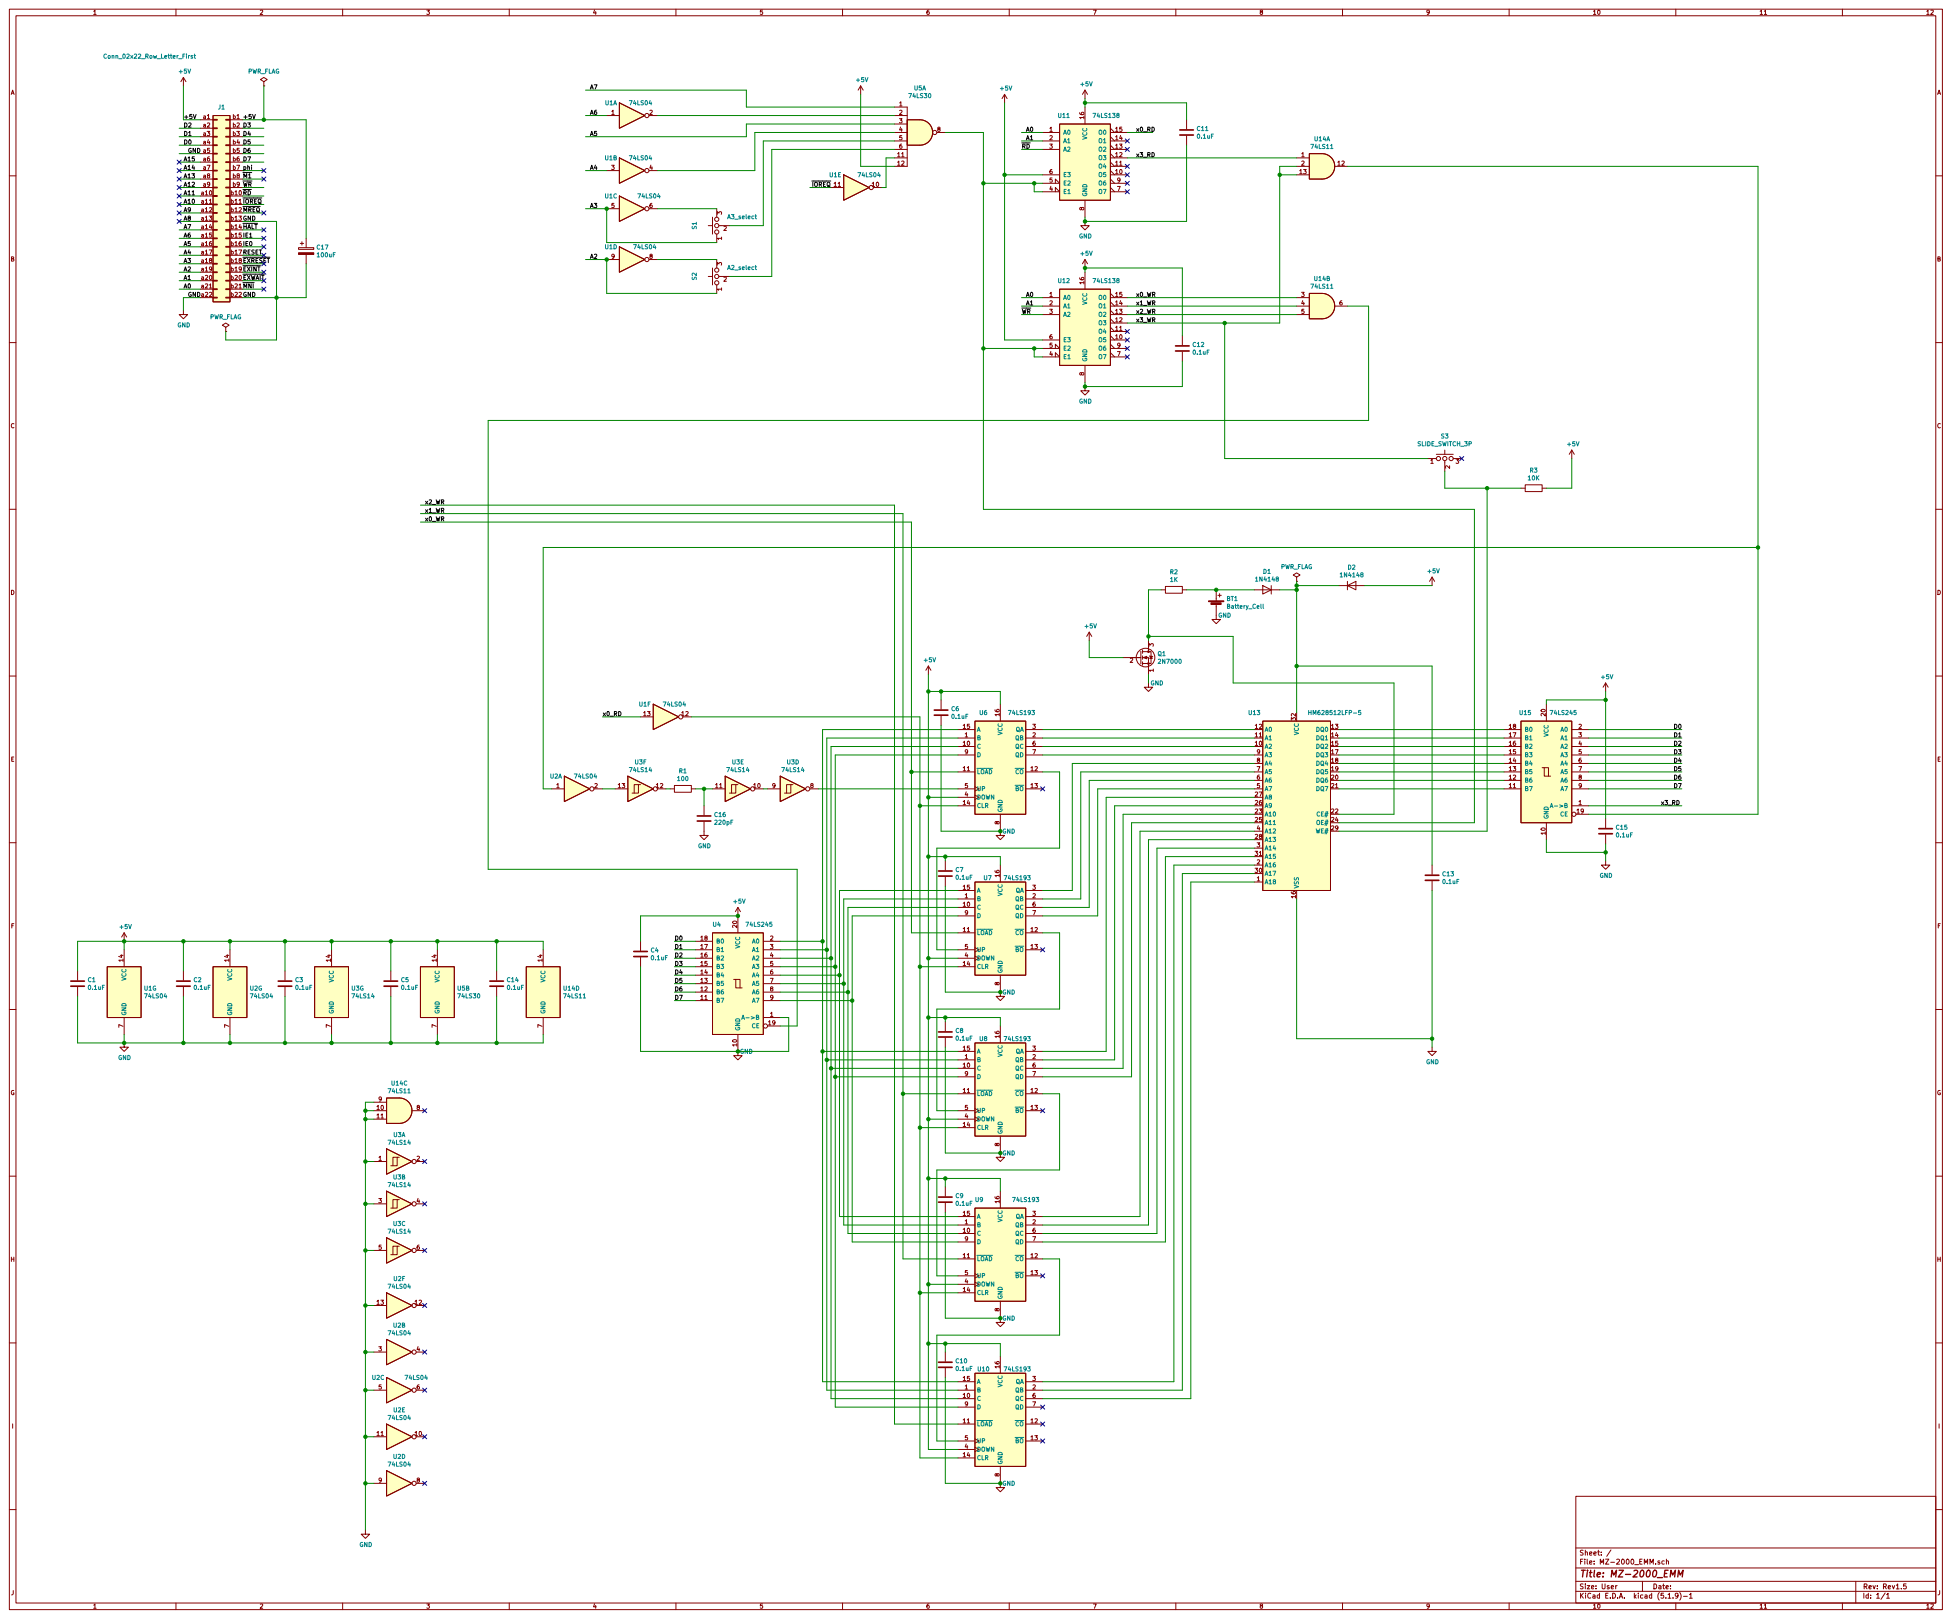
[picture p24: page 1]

x1_WR
x2_WR
x3_WR

20 DQ7
21 CE#

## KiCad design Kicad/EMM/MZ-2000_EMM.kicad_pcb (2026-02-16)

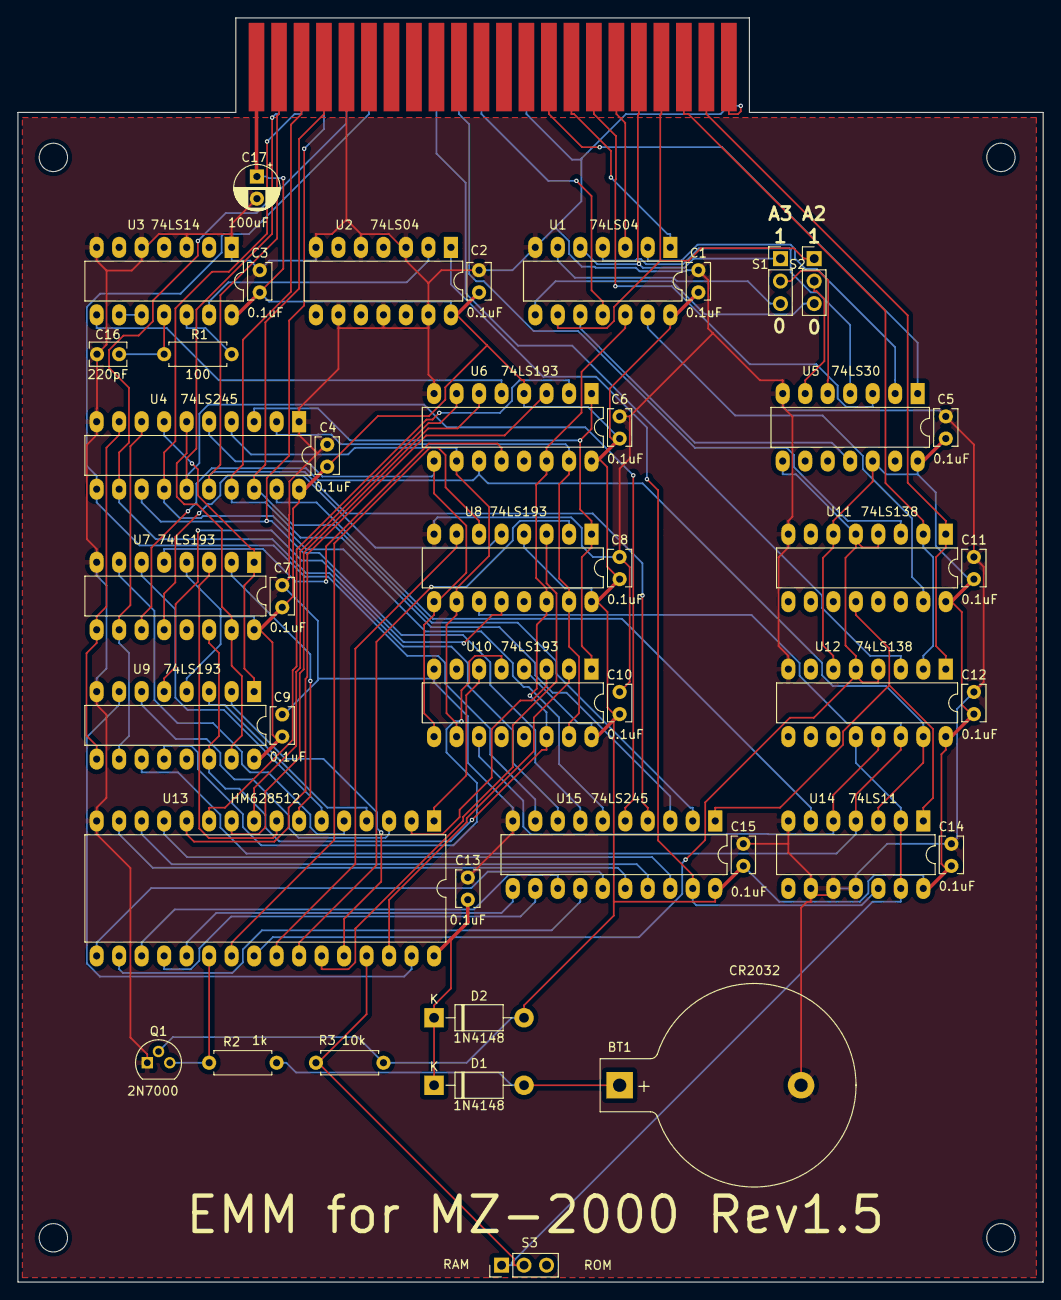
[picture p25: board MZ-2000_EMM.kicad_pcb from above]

Board: 2 copper layers, 115.8 x 142.7 mm, 47 parts (0 on the bottom side), 86 nets.

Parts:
BT1: Battery_Cell; BatteryHolder_Keystone_103_1x20mm
C1, C2, C3, C4, C5, C6, C7, C8, C9, C10, C11, C12, C13, C14, C15: 0.1uF; C_Rect_L4.0mm_W2.5mm_P2.50mm
C16: 220pF; C_Rect_L4.0mm_W2.5mm_P2.50mm
C17: 100uF; CP_Radial_D5.0mm_P2.50mm
D1, D2: 1N4148; D_DO-41_SOD81_P10.16mm_Horizontal
J1: Conn_02x22_Row_Letter_First; BUS_MZ2000
MH1, MH2, MH3, MH4: MountingHole_3.2mm_M3
Q1: 2N7000; TO-92
R1: 100; R_Axial_DIN0207_L6.3mm_D2.5mm_P7.62mm_Horizontal
R2: 1K; R_Axial_DIN0207_L6.3mm_D2.5mm_P7.62mm_Horizontal
R3: 10K; R_Axial_DIN0207_L6.3mm_D2.5mm_P7.62mm_Horizontal
S1: A3_select; PinHeader_1x03_P2.54mm_Vertical
S2: A2_select; PinHeader_1x03_P2.54mm_Vertical
S3: SLIDE_SWITCH_3P; PinHeader_1x03_P2.54mm_Vertical
U1, U2: 74LS04; DIP-14_W7.62mm_LongPads
U3: 74LS14; DIP-14_W7.62mm_LongPads
U4, U15: 74LS245; DIP-20_W7.62mm_LongPads
U5: 74LS30; DIP-14_W7.62mm_LongPads
U6, U7, U8, U9, U10: 74LS193; DIP-16_W7.62mm_LongPads
U11, U12: 74LS138; DIP-16_W7.62mm_LongPads
U13: HM628512LFP-5; DIP-32_W15.24mm_LongPads
U14: 74LS11; DIP-14_W7.62mm_LongPads

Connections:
+5V: C1.1, C2.1, C3.1, C4.1, C5.1, C6.1, C7.1, C8.1, C9.1, C10.1, C11.1, C12.1, C14.1, C15.1, C17.1, D2.2, J1.a1, J1.b1, Q1.2, R3.2, U1.14, U2.14, U3.14, U4.20, U5.12, U5.14, U6.4, U6.16, U7.4, U7.16, U8.4, U8.16, U9.4, U9.16, U10.4, U10.16, U11.6, U11.16, U12.6, U12.16, U14.14, U15.20
/A0: J1.a21, U11.1, U12.1
/A1: J1.a20, U11.2, U12.2
/A2: J1.a19, S2.1, U1.9
/A3: J1.a18, S1.1, U1.5
/A4: J1.a17, U1.3
/A5: J1.a16, U5.3
/A6: J1.a15, U1.1
/A7: J1.a14, U5.1
/D0: J1.a4, U4.18, U15.2
/D1: J1.a3, U4.17, U15.3
/D2: J1.a2, U4.16, U15.4
/D3: J1.b2, U4.15, U15.5
/D4: J1.b3, U4.14, U15.6
/D5: J1.b4, U4.13, U15.7
/D6: J1.b5, U4.12, U15.8
/D7: J1.b6, U4.11, U15.9
/x0_RD: U1.13, U11.15
/x0_WR: U6.11, U7.11, U12.15, U14.3
/x1_WR: U8.11, U9.11, U12.14, U14.4
/x2_WR: U10.11, U12.13, U14.5
/x3_RD: U11.12, U14.1, U15.1
/x3_WR: S3.1, U12.12, U14.2, U14.13
/~IOREQ: J1.b11, U1.11
/~RD: J1.b10, U11.3
/~WR: J1.b9, U12.3
GND: BT1.2, C1.2, C2.2, C3.2, C4.2, C5.2, C6.2, C7.2, C8.2, C9.2, C10.2, C11.2, C12.2, C13.2, C14.2, C15.2, C16.2, C17.2, J1.a5, J1.a22, J1.b13, J1.b22, Q1.1, U1.7, U2.3, U2.5, U2.7, U2.9, U2.11, U2.13, U3.1, U3.3, U3.5, U3.7, U4.1, U4.10, U5.7, U6.8, U7.8, U8.8, U9.8, U10.8, U11.8, U12.8, U13.16, U14.7, U14.9, U14.10, U14.11, U15.10
unnamed: BT1.1, D1.2, R2.2
unnamed: C13.1, D1.1, D2.1, U13.32
unnamed: C16.1, R1.2, U3.11
unnamed: Q1.3, R2.1, U13.22
unnamed: R1.1, U3.12
unnamed: R3.1, S3.2, U13.29
unnamed: S1.2, U5.5
unnamed: S1.3, U1.6
unnamed: S2.2, U5.6
unnamed: S2.3, U1.8
unnamed: U1.2, U5.2
unnamed: U1.4, U5.4
unnamed: U1.10, U5.11
unnamed: U1.12, U6.14, U7.14, U8.14, U9.14, U10.14
unnamed: U2.2, U3.13
unnamed: U3.8, U6.5
unnamed: U3.9, U3.10
unnamed: U4.6, U7.15, U9.15
unnamed: U4.7, U7.1, U9.1
unnamed: U4.8, U7.10, U9.10
unnamed: U4.9, U7.9, U9.9
unnamed: U6.12, U7.5
unnamed: U7.12, U8.5
unnamed: U8.12, U9.5
unnamed: U4.3, U6.1, U8.1, U10.1
unnamed: U10.2, U13.30
unnamed: U10.3, U13.2
unnamed: U9.12, U10.5
unnamed: U10.6, U13.1
unnamed: U4.5, U6.9, U8.9, U10.9
unnamed: U4.4, U6.10, U8.10, U10.10
unnamed: U4.2, U6.15, U8.15, U10.15
unnamed: U5.8, U11.4, U11.5, U12.4, U12.5, U13.24
unnamed: U9.6, U13.3
unnamed: U9.3, U13.4
unnamed: U7.7, U13.5
unnamed: U7.6, U13.6
unnamed: U7.2, U13.7
unnamed: U7.3, U13.8
unnamed: U6.7, U13.9
unnamed: U6.6, U13.10
unnamed: U6.2, U13.11
unnamed: U6.3, U13.12
unnamed: U13.13, U15.18
unnamed: U13.14, U15.17
unnamed: U13.15, U15.16
unnamed: U13.17, U15.15
unnamed: U13.18, U15.14
unnamed: U13.19, U15.13
unnamed: U13.20, U15.12
unnamed: U13.21, U15.11
unnamed: U8.6, U13.23
unnamed: U8.7, U13.25
unnamed: U8.2, U13.26
unnamed: U8.3, U13.27
unnamed: U9.2, U13.28
unnamed: U9.7, U13.31
unnamed: U4.19, U14.6
unnamed: U2.1, U14.12, U15.19
